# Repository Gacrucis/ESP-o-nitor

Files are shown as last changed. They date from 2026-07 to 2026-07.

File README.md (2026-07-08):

# ESP-o-nitor

A physical usage monitor for Claude and Codex. A host service reads each tool's quota and
activity and feeds an ESP32 display that shows, at a glance, how much of your 5h and weekly
windows is left and whether each tool is working, waiting or idle.

The heavy lifting (reading quota, tracking activity, deciding pace) always happens in the host
service. What changes between builds is only the **display hardware**, so the firmware comes in
two variants that talk to the **same** service:

```
                                   /--HTTP frames--> [OLED ESP32] --I2C--> 2x SSD1306 128x64 (mono)
[monitor-service (PC/Docker)] -----|
   reads quota + activity          \--HTTP JSON----> [CYD ESP32]  --SPI--> 1x ILI9341 320x240 (color)
```

| Variant | Hardware | How it draws |
| --- | --- | --- |
| **OLED** | 2x SSD1306 128x64 mono (I2C), one screen per tool | The service renders the 1-bit framebuffers and the ESP just projects them (`/api/esp/frames`). |
| **CYD** | 1x ILI9341 320x240 color (ESP32-2432S028R "Cheap Yellow Display"), both tools on one screen | The ESP draws in color on-device from a ~1 KB JSON snapshot (`/api/esp/snapshot`). |

Pick one variant per device; the service supports both at once with no changes.

## Repository layout

| Folder | Contents |
| --- | --- |
| [`monitor-service/`](monitor-service/) | Host service (Python). Reads Claude/Codex quota, detects activity, renders the OLED frames and serves everything over HTTP. Includes a live configuration web UI. Shared by both firmware variants. |
| [`firmware/oled/`](firmware/oled/) | OLED firmware (PlatformIO, C++): projects the framebuffers the service renders, animates the activity corner and shows local screensavers. |
| [`firmware/cyd/`](firmware/cyd/) | CYD firmware (PlatformIO, C++): draws both tools in color natively from the JSON snapshot. |
| [`3d-models/`](3d-models/) | Printable enclosure for the OLED dual-screen build (STEP + STL with PNG previews): case and lid for the board plus the base and lids that hold the two screens. |

Each folder has its own README with architecture, requirements and commands.

## Getting started

1. **Host service** ([`monitor-service/`](monitor-service/)): run it with Docker
   (`docker compose up -d --build`) or locally. It serves the web UI at `http://localhost:8765`
   and the `/api/esp/*` endpoints the devices consume. This step is the same for both variants.
2. **Firmware**: build and flash the variant that matches your hardware with PlatformIO (USB or
   OTA), then point the device at the service URL (`http://PC_IP:8765`) from its own
   configuration web page.
   - OLED: [`firmware/oled/`](firmware/oled/)
   - CYD: [`firmware/cyd/`](firmware/cyd/)

## How the pieces fit

- The service builds a usage snapshot (remaining percentage, 5h/weekly windows, expected pace)
  and exposes it under `/api/esp/*`. The OLED variant consumes pre-rendered frames
  (`/api/esp/frames`); the CYD variant consumes the raw snapshot (`/api/esp/snapshot`) and draws
  it in color itself.
- Activity (working / waiting / idle) arrives via long-poll (`/api/esp/activity-wait`) so either
  device reacts almost instantly and drives its activity animation.
- Almost everything (theme, labels, animation, screensaver, brightness, manual usage) is set from
  the service web UI and applied on the device's next poll, without reflashing. You only reflash
  when the firmware itself changes (`firmware/<variant>/src/main.cpp`, its `platformio.ini` or its
  dependencies).

## Development

- **Host service** (`monitor-service/`): runs with hot reload via `watchmedo`, mounting
  `monitor-service/src` into the container. For changes to Python, embedded HTML, CSS or service
  logic there is no need to restart or run Docker; the live service reloads on its own. Validate
  with `python -m compileall monitor-service/src` and, when relevant, against the HTTP endpoints
  of the already running service. Only use Docker commands when the container configuration,
  dependencies, `Dockerfile` or `docker-compose.yml` change, or if the live service stops
  responding.
- **Firmware** (`firmware/oled/`, `firmware/cyd/`): only needs reflashing when that variant's
  `src/main.cpp`, `platformio.ini` or PlatformIO dependencies change. See each variant's README
  for the build and flash commands (USB and OTA).

## License

Released under the MIT License. See [LICENSE](LICENSE).

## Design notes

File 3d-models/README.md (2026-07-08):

# 3d-models

Printable enclosure for the **OLED variant** of ESP-o-nitor ([`../firmware/oled/`](../firmware/oled/)):
the ESP32 dev board plus the two OLED SSD1306 128x64 displays. Each part is provided both as STEP
(ISO 10303, editable in CAD) and as STL (ready to slice).

The **CYD variant** ([`../firmware/cyd/`](../firmware/cyd/)) is not covered here: it is a single
self-contained board (ESP32-2432S028R), so any off-the-shelf horizontal CYD case works - search
"CYD" or "ESP32-2432S028R" on [printables.com](https://www.printables.com/) or
[makerworld.com](https://makerworld.com/).

- [`STEP/`](STEP/) - solid models (FreeCAD, Fusion 360, etc.).
- [`STL/`](STL/) - meshes ready for a slicer (PrusaSlicer, Cura, etc.).
- [`previews/`](previews/) - PNG render of each part.

## Parts

| Part | Qty | Purpose | Preview |
| --- | --- | --- | --- |
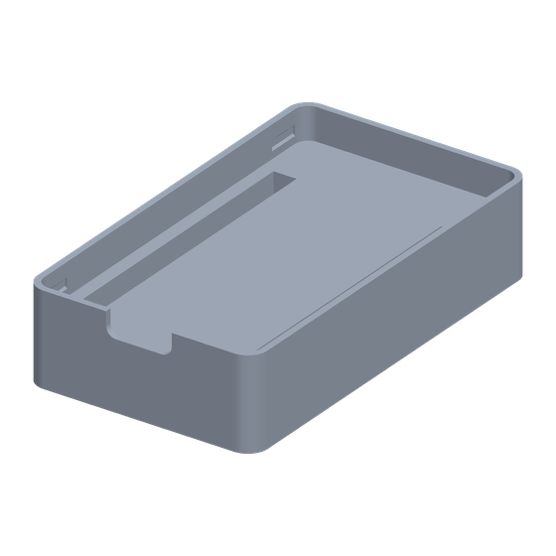
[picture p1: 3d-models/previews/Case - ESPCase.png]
ESPCase
| `Case - ESPCase` | 1 | Housing for the ESP32 board. |  |
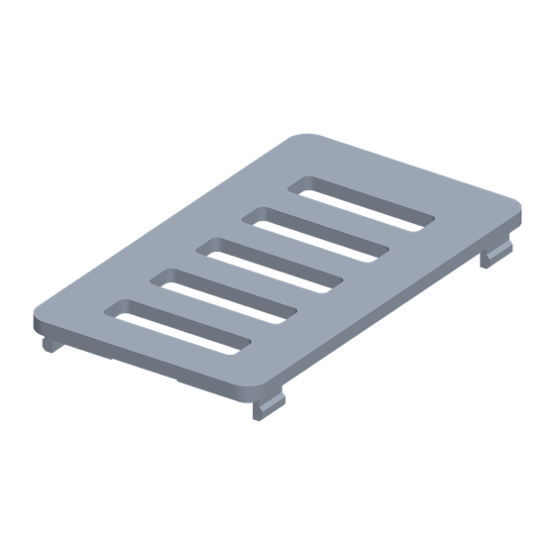
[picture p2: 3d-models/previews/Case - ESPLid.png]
ESPLid
| `Case - ESPLid` | 1 | Lid for the ESP32 housing. |  |
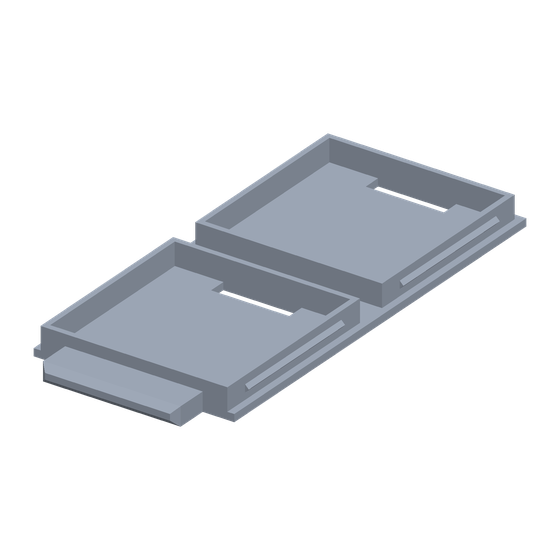
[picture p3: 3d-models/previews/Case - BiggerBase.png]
BiggerBase
| `Case - BiggerBase` | 1 | Base that holds the two OLED SSD1306 (128x64) displays. |  |
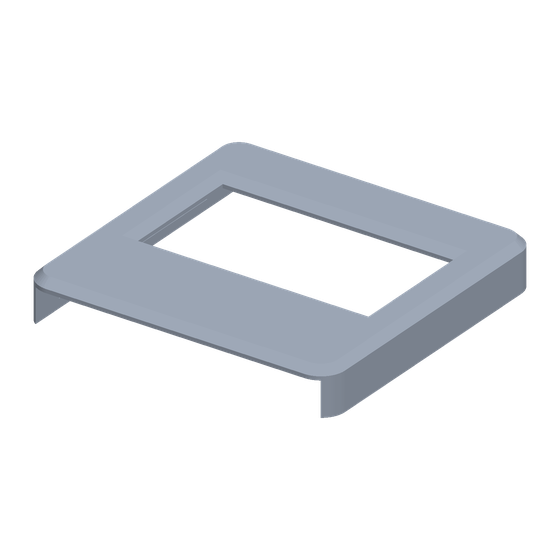
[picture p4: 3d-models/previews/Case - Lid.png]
Lid
| `Case - Lid` | 2 | Bezel/lid for the display base - one per display. |  |

You need **2 units of `Case - Lid`** for the display base (one bezel per screen). Every other part
is printed once. Together they make up the enclosure for the ESP32 and the two screens.

## Notes

- STEP is a solid-model format: open the `STL/` files directly in a slicer to generate the
  printing G-code, or the `STEP/` files in CAD to adjust them.

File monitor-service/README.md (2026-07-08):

# monitor-service

Local service that feeds the [ESP-o-nitor firmware](../firmware/) with Claude and Codex usage. It
reads each tool's quota and activity, and serves it over HTTP to whichever display variant is
connected. It includes a live configuration web UI.

It backs both firmware variants from the same snapshot:

- [OLED](../firmware/oled/): the service renders the two screens (128x64, 1 bit) as framebuffers
  and the device only projects them.
- [CYD](../firmware/cyd/): the service exposes the raw JSON snapshot and the device draws it in
  color itself.

## How it works

- Builds a usage snapshot (remaining percentage, 5h/weekly windows, expected pace). It is served
  raw at `/api/esp/snapshot` (consumed by the CYD).
  - Claude: usage OAuth endpoint.
  - Codex: local `rate_limits` snapshots from the rollouts.
- Renders each OLED screen with Pillow according to the selected theme and serves it as a
  framebuffer at `/api/esp/frames` (with cache and ETag so it is not rebuilt on every ESP poll).
- Detects activity (working / waiting / idle) and delivers it via long-poll so the ESP reacts
  almost instantly.
- Packs the corner animation (configurable style + size) into a binary that the ESP downloads
  once (re-downloaded only if the ETag changes).
- Measures ESP telemetry (last poll, cadence, IP) to show in the web UI whether it is connected
  and when a freshly saved change will take effect.

## Requirements

- Python >= 3.12 and Pillow + watchdog (see `pyproject.toml`), or Docker.
- Read-only access to `~/.claude` and `~/.codex` (where quota and activity are read from).

## Run with Docker (recommended)

```bash
docker compose up -d --build
```

The web UI is at `http://localhost:8765`. The `docker-compose.yml`:

- Mounts `./src` for hot reload (when you edit the code on the host, `watchmedo` restarts the
  service).
- Mounts `~/.claude` and `~/.codex` as read-only.
- Persists the configuration in the `monitor-service-data` volume (`/app/data/config.json`).

Logs and status:

```bash
docker compose ps
docker compose logs --tail 80
```

## Run without Docker

```bash
pip install pillow==11.0.0 watchdog==6.0.0
export CONFIG_PATH=./data/config.json
export CLAUDE_HOME="$HOME/.claude"
export CODEX_HOME="$HOME/.codex"
export SERVICE_HOST=0.0.0.0
export SERVICE_PORT=8765
PYTHONPATH=src python -m monitor_service.main
```

## Environment variables

| Variable | Description |
| --- | --- |
| `CONFIG_PATH` | Path of the persistent `config.json` (required). |
| `CLAUDE_HOME` / `CODEX_HOME` | Claude and Codex directories (read-only). |
| `SERVICE_HOST` / `SERVICE_PORT` | HTTP server host and port. |
| `FRAME_CACHE_TTL_SECONDS` | Minimum interval between ESP frame regenerations. |
| `CLAUDE_USAGE_TTL_SECONDS` | Minimum interval between real Claude usage queries. |
| `CODEX_USAGE_TTL_SECONDS` | Minimum interval between local Codex reads. |

Most settings (theme, labels, animation, screensaver, dimming, manual usage) are edited from the
web UI and saved in `config.json`; the variables only set the initial default values.

## Configuration web UI

`http://localhost:8765` offers:

- Home: Claude/Codex cards, ESP32 device status (live) and a preview of both screens.
- Usage: manual percentages and windows (5h / weekly).
- Settings: labels, tolerance, cache TTLs, anti burn-in dimming, activity animation (style, speed
  and box size), theme and screensavers.

On save, the web UI estimates when it will take effect based on the ESP's real poll cadence and
confirms once the device applies it.

## Main endpoints

Web / configuration:

- `GET /` - web interface.
- `GET /api/config` / `POST /api/config` - read / save configuration.
- `POST /api/usage/manual` - set manual usage.
- `GET /api/status` - diagnostics of paths and sources.
- `GET /api/esp/status` - ESP telemetry (online, last poll, cadence, IP).
- `GET /api/themes` - available themes.

Consumed by the ESP32:

- `GET /api/esp/frames` - framebuffers of both screens (octet-stream, ETag).
- `GET /api/esp/activity-wait` - activity long-poll.
- `GET /api/esp/activity-animation` - binary package of the corner animation.

Previews (web):

- `GET /api/esp/snapshot` - JSON snapshot.
- `GET /api/esp/preview/{claude|codex}.png` - screen preview.
- `GET /api/esp/activity-preview.gif` - animation preview.
- `GET /api/esp/screensaver-preview.gif` - screensaver preview.

## Structure

- `src/monitor_service/main.py` - HTTP server, embedded web UI and endpoints.
- `renderer.py` - screen rendering (delta theme).
- `activity_animation.py` - generation and packaging of the corner animation.
- `screensavers.py` - screensaver previews.
- `usage.py` / `claude_usage.py` / `collectors.py` - quota and activity reading.
- `config.py` / `types.py` - configuration loading, normalization and types.

## Theme and styles

- Screen theme: `delta` (terminal-style columns with remaining %, pace delta and reset, plus a
  solid bar marking the value expected from the linear regression).
- Animation styles: `spinner`, `dots`, `dots-right`, `stars-right`, `pulse`, `bars`, `ball`,
  `wave`, `worm`. The box size is configurable and the animations adapt to it.
- Screensavers (rendered locally by the ESP): `black`, `snake`, `pipes`, `matrix`, `dvd`, `maze`,
  `flower`.

## Development

- With Docker, hot reload is already active; editing `src/` restarts the service on its own.
- Quick validation: `python -m compileall src`.

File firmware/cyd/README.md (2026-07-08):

# ESP-o-nitor - CYD firmware

The **CYD variant** of [ESP-o-nitor](../../): firmware for a **CYD** (Cheap Yellow Display,
ESP32-2432S028R) with a 320x240 color ILI9341 screen that acts as a physical usage monitor for
Claude and Codex.

Unlike the [OLED variant](../oled/), which projects the framebuffers the service renders, the CYD
**draws in color on-device** from the JSON snapshot exposed by the
[monitor-service](../../monitor-service/). Both variants use the same service, unchanged.

## Architecture

```
[monitor-service (PC/Docker)] --HTTP JSON--> [CYD/ESP32] --SPI--> ILI9341 320x240
      computes quota/activity    /api/esp/*     draws       Claude (top) + Codex (bottom)
```

- Polls `GET /api/esp/snapshot` every `pollIntervalMs` and draws both panels.
- Uses `GET /api/esp/activity-wait` (non-blocking long-poll) to react almost instantly to the
  busy / waiting / idle states and animate each tool's activity indicator.
- Only redraws when the data changes (signature comparison); the activity spinner refreshes just
  its own box so the rest of the screen does not flicker.
- If the service does not respond it shows "No service"; if there is no WiFi it brings up a
  configuration AP.

Sending ~1 KB of JSON per poll instead of full framebuffers keeps the wire cheap, exploits the
color panel, and needs no changes on the service side.

## What it shows

For each tool (Claude / Codex), on its half of the screen:

- Icon + name and an activity indicator (BUSY with spinner / WAIT blinking / IDLE).
- The **5H** (current) and **WK** (weekly) windows, each with:
  - Remaining percentage and the delta against what the linear regression expects (+margin ahead
    / -behind).
  - A usage bar colored by pace (green below, blue on pace, amber above, red when very little is
    left) with a vertical mark for the expected value.
  - Time until reset.

## Hardware (ESP32-2432S028R)

- ESP32-WROOM-32 with a 320x240 SPI ILI9341 panel and a resistive XPT2046 touch (unused).
- Panel pinout (fixed by `build_flags` in `platformio.ini`):
  SCLK 14, MOSI 13, MISO 12, CS 15, DC 2, RST -1, backlight (BL) GPIO 21.
- Backlight driven by PWM (LEDC) to dim on inactivity.
- The RGB LED (GPIO 4/16/17, active low) is turned off at boot.

## Requirements

- [PlatformIO](https://platformio.org/) (CLI or VS Code extension).
- Dependencies (resolved by PlatformIO): TFT_eSPI, ArduinoJson.

## Credentials (WiFi and OTA)

1. Copy `include/secrets.example.h` to `include/secrets.h` and set the SSID, WiFi password, OTA
   password and (optionally) the default service URL. `secrets.h` is ignored by git.
2. For OTA flashing, copy `platformio_override.example.ini` to `platformio_override.ini` with the
   same OTA password in `--auth`.

Without `secrets.h` it builds with empty values: the CYD boots into the `CYD-Emergencia` AP
(password `configcyd0`) and you configure WiFi/service from `http://192.168.4.1`.

## Build and flash

Run from this `firmware/cyd/` folder.

**Linux.** The CYD reuses the OLED variant's PlatformIO `.venv`, so no separate install is needed:

```bash
# Build
../oled/.venv/bin/python3 -m platformio run -e cyd
# Flash over USB (the CYD ships a CH340, usually /dev/ttyUSB0)
../oled/.venv/bin/python3 -m platformio run -e cyd -t upload --upload-port /dev/ttyUSB0
# Flash over OTA (with the CYD on the network as cyd.local)
../oled/.venv/bin/python3 -m platformio run -e cyd_ota -t upload
```

**macOS.** The bundled `.venv/` is a local Linux artifact and is not in the repository, so install
PlatformIO once and use the system `pio` (replace `../oled/.venv/bin/python3 -m platformio` with
`pio` in every command above):

```bash
brew install platformio          # or: pip3 install platformio
# Build
pio run -e cyd
# Flash over USB (the CYD ships a CH340; on macOS it shows up as /dev/cu.wchusbserial*)
pio run -e cyd -t upload --upload-port /dev/cu.wchusbserial-0001
# Flash over OTA
pio run -e cyd_ota -t upload
```

- On macOS use the `cu.*` node, never `tty.*`. If the port does not appear, install the WCH CH34x
  driver (the CYD uses a CH340 USB-serial chip). There is no `dialout` group or `sudo`: the port
  works as-is.
- List the available ports with `pio device list` (or `.venv/bin/python3 -m platformio device list`
  on Linux).

If USB upload fails, lower `upload_speed` in `platformio.ini` (921600 -> 460800 -> 115200).

## Configuration

Booting without valid WiFi brings up the `CYD-Emergencia` AP. Connect and open
`http://192.168.4.1` to set the SSID, password and service URL (`http://PC_IP:8765`). Once on the
network the CYD is reachable at `http://cyd.local` to reconfigure the service, rotation,
brightness, dimming and poll interval, and for web OTA.

## Structure

- `src/main.cpp` - the entire firmware (setup, loop, WiFi/AP, web, OTA, polling and rendering).
- `platformio.ini` - build environments and the TFT_eSPI configuration for the CYD.

## Relationship with the service

This firmware depends on the service in [monitor-service/](../../monitor-service/), which exposes
the `/api/esp/*` endpoints. It consumes `GET /api/esp/snapshot` (data) and
`GET /api/esp/activity-wait` (activity long-poll). It also hits `GET /api/esp/frames` with an
`If-None-Match`, but only to read the `X-Sessions-*` session-count headers off the 304 response;
it never downloads the framebuffer. Theme colors, labels, brightness and usage data
are set in the service web UI and applied on the next poll, without reflashing. You only reflash
when `src/main.cpp`, `platformio.ini` or the PlatformIO dependencies change.

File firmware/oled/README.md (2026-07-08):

# ESP-o-nitor - OLED firmware

The **OLED variant** of [ESP-o-nitor](../../): firmware for an ESP32 with two SSD1306 OLED
displays (128x64) that act as a physical usage monitor for Claude and Codex. The ESP32 computes
nothing: it only projects the framebuffers produced by the [monitor-service](../../monitor-service/),
animates the activity corner and shows local screensavers when the service does not respond.

For the color single-screen build see the [CYD variant](../cyd/); both talk to the same service.

## Architecture

```
[monitor-service (PC/Docker)]  --HTTP-->  [ESP32]  --I2C-->  2x OLED SSD1306
        renders 128x64 1-bit             projects            Claude / Codex
```

- The service draws each screen (128x64, 1 bit) and serves it at `/api/esp/frames`.
- The ESP32 polls that endpoint and copies the bitmap straight to the OLED (it never interprets
  the content).
- Activity (working / waiting / idle) arrives via long-poll and headers, and drives the animation
  in the top-right corner; while waiting for a response the screen blinks inverted.
- The animation package is downloaded once and kept in RAM; it is re-downloaded only if its ETag
  changes.
- If the service is down, the ESP shows a local screensaver (anti burn-in).

## Hardware

- Board: ESP32 dev (`board = esp32dev`).
- 2x OLED SSD1306 128x64 over I2C, on separate buses (one `TwoWire` per display).
- Default I2C pins (configurable from the ESP web UI):
  - Claude: SDA 21, SCL 22, address `0x3C`.
  - Codex: SDA 16, SCL 17, address `0x3C`.

## Features

- Projection of 128x64 framebuffers from the service.
- Activity animation in the corner (size and style configurable from the service).
- Blinking screen inversion when a tool is waiting for the user.
- Local anti burn-in screensavers: black, snake, pipes, matrix, dvd, maze, flower.
- Brightness dimming on inactivity (decided by the service via the `X-Brightness` header).
- Built-in web server on port 80 to configure WiFi, service URL, pins and displays.
- Emergency AP mode when it cannot connect to WiFi (portal at `http://192.168.4.1`).
- Network OTA (ArduinoOTA, port 3232) and web OTA.
- Configuration persistence in NVS (`Preferences`).
- mDNS: the device is reachable as `esp32.local`.

## Structure

- `src/main.cpp` - the entire firmware (setup, loop, web server, OTA, rendering, screensavers).
- `platformio.ini` - build environments and dependencies.

## Requirements

- [PlatformIO](https://platformio.org/) (CLI or VS Code extension).
- Dependencies (resolved automatically by PlatformIO): Adafruit SSD1306, Adafruit GFX,
  ArduinoJson.

## Credentials (WiFi and OTA)

The firmware ships no credentials in the source. To set local default values:

1. Copy `include/secrets.example.h` to `include/secrets.h` and put your SSID, WiFi password and
   OTA password there. You may also set `SECRET_SERVICE_URL` to your PC's service URL (leave it
   empty to configure it later from the web UI). That file is ignored by git and never versioned.
2. For OTA flashing, copy `platformio_override.example.ini` to `platformio_override.ini` and put
   the same OTA password in `--auth`. PlatformIO applies it automatically on top of
   `platformio.ini`; it is ignored by git too.

Without `secrets.h`, the firmware builds with empty credentials: the ESP boots into the emergency
AP and you configure WiFi/service from its web UI. The OTA password must match between
`secrets.h` (running firmware) and `platformio_override.ini` (OTA upload).

## Build and flash

### Toolchain (PlatformIO in the project `.venv`)

All commands in this section run from the `esp32/` folder (where `platformio.ini` and `.venv/`
live).

PlatformIO 6.1.19 lives in the project `.venv`. The `.venv/bin/pio` launcher kept a shebang
inherited from another project (it points to a non-existent Python), so the module is invoked
with the venv's Python, which does work:

```bash
.venv/bin/python3 -m platformio <command>
```

To get `pio` back directly, reinstall the launcher once:

```bash
.venv/bin/python3 -m pip install --force-reinstall platformio
```

(If you already have PlatformIO on the system PATH, just use `pio <command>`.)

**macOS**: the bundled `.venv/` is a local Linux artifact and is not part of the repository, so on
Mac you install PlatformIO separately (once) and use the system `pio`:

```bash
brew install platformio          # or: pip3 install platformio
pio run -e esp32dev              # replaces `.venv/bin/python3 -m platformio ...`
```

In the rest of this guide, replace `.venv/bin/python3 -m platformio` with `pio`.

### Over USB (first flash or if OTA fails)

Connect the ESP32 over USB. PlatformIO auto-detects the serial port; force it with `--upload-port`
if there are several devices. To list the available ports:

```bash
.venv/bin/python3 -m platformio device list
```

```bash
.venv/bin/python3 -m platformio run -e esp32dev -t upload
# explicit port, optional:
.venv/bin/python3 -m platformio run -e esp32dev -t upload --upload-port <port>
```

**Linux**

- Typical ports: `/dev/ttyUSB0` (CP210x/CH340 chip) or `/dev/ttyACM0` (native USB).
- If the port is permission denied, add your user to the `dialout` group
  (`sudo usermod -aG dialout $USER`) and restart the session.

**macOS**

- Typical ports: `/dev/cu.usbserial-*` or `/dev/cu.SLAB_USBtoUART` (CP210x),
  `/dev/cu.wchusbserial*` (CH340). Always use the `cu.*` node, not `tty.*`.
- Modern macOS (11+) already ships the CP210x and CH340 drivers. If the port does not appear,
  install the chip vendor's driver: Silicon Labs CP210x VCP or WCH CH34x.
- There is no `dialout` group or permission tweak: the port works without `sudo`.

```bash
# example on macOS with an explicit port:
.venv/bin/python3 -m platformio run -e esp32dev -t upload --upload-port /dev/cu.usbserial-0001
```

### Over OTA (with the ESP already on the network, reachable as `esp32.local`)

```bash
.venv/bin/python3 -m platformio run -e esp32dev_ota -t upload
# if mDNS does not resolve, point at the ESP's IP:
.venv/bin/python3 -m platformio run -e esp32dev_ota -t upload --upload-port 192.168.1.xxx
```

The `esp32dev_ota` environment uses `espota` against `esp32.local` with the password defined in
`platformio_override.ini` (`--auth=...`, see [Credentials](#credentials-wifi-and-ota)). It must
match the OTA password of the running firmware; if you change one, change the other.

### Build only (no upload)

```bash
.venv/bin/python3 -m platformio run -e esp32dev
```

The default WiFi and OTA credentials come from `include/secrets.h` (see
[Credentials](#credentials-wifi-and-ota)); at runtime they are changed from the ESP web UI.

## First boot and configuration

1. After flashing, if the ESP cannot connect to the configured WiFi, it brings up the emergency
   AP `ESP32-Emergencia`. Connect to it and open `http://192.168.4.1`.
2. Configure the SSID, password and the service URL (for example `http://PC_IP:8765`).
3. Once on the network, the ESP is reachable at `http://esp32.local` to reconfigure pins,
   displays, contrast and to check status.

## Relationship with the service

This firmware depends on the service in [monitor-service/](../../monitor-service/), which exposes the
`/api/esp/*` endpoints the ESP consumes. Changes to animation style/size, theme, screensavers,
brightness and usage data are made in the service web UI and applied on the ESP's next poll,
without reflashing. You only need to reflash when `src/main.cpp`, `platformio.ini` or the
PlatformIO dependencies change.

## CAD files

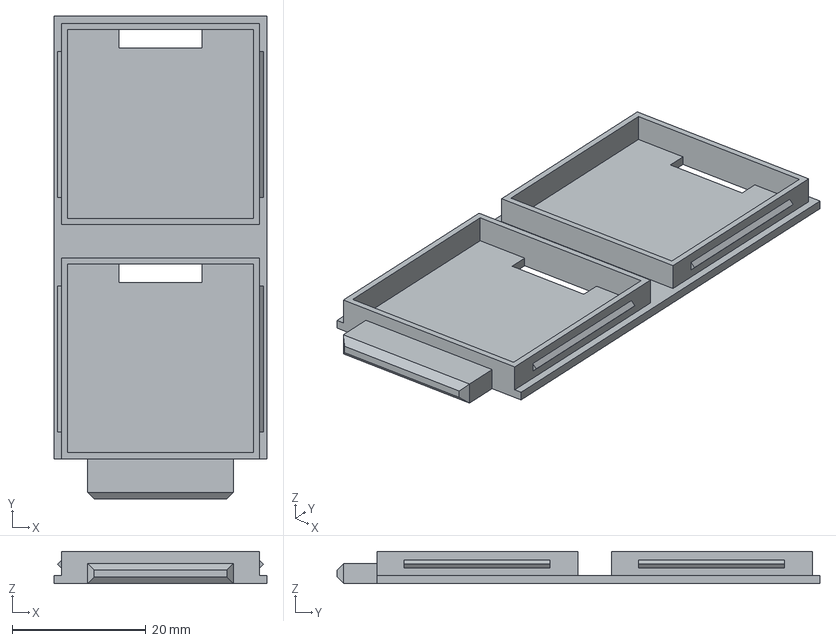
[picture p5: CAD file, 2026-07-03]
3d-models/STEP/Case - BiggerBase.step
31.8 x 72.1 x 4.80 mm

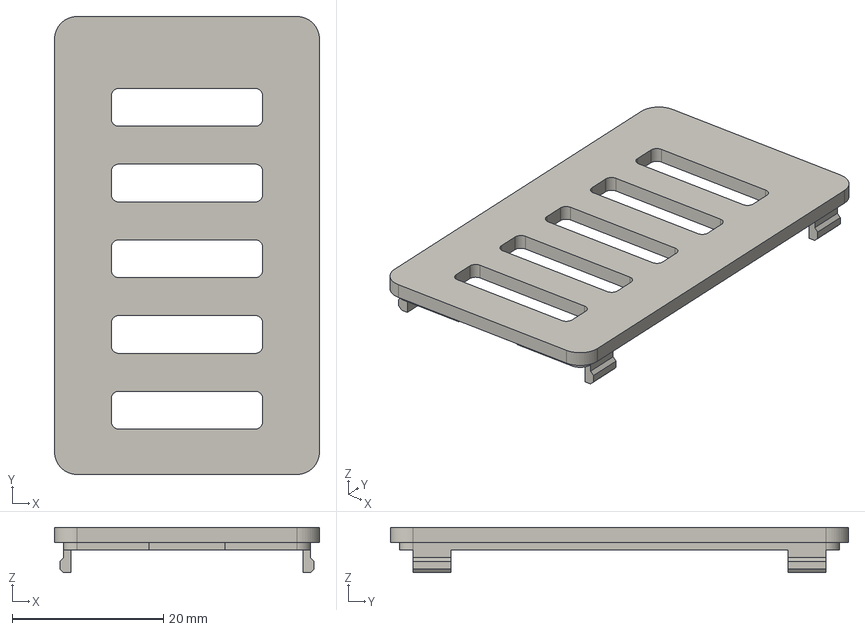
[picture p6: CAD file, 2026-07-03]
3d-models/STEP/Case - ESPLid.step
35.0 x 60.5 x 6.00 mm

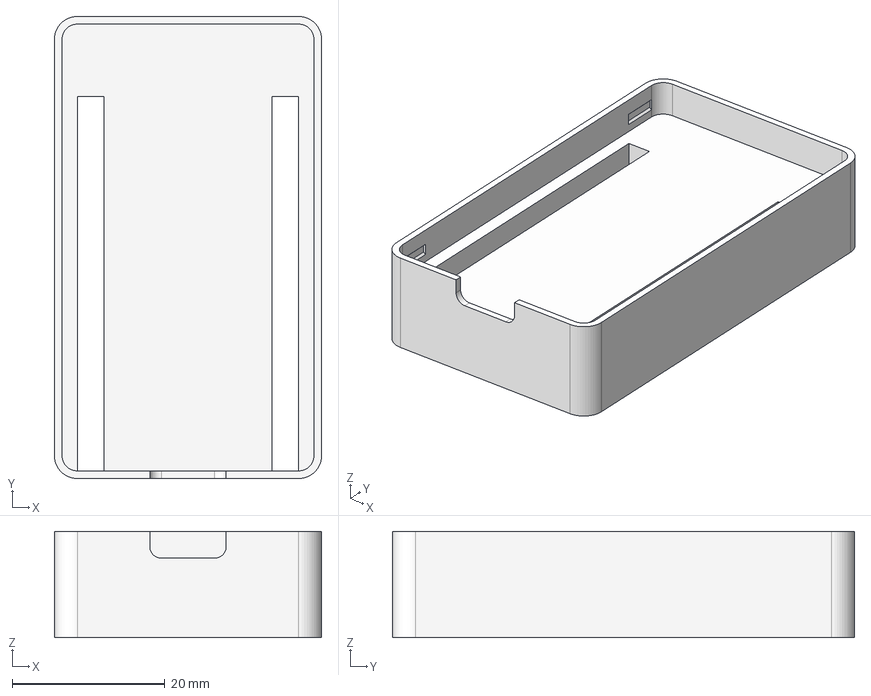
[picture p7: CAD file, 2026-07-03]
3d-models/STEP/Case - ESPCase.step
35.0 x 60.5 x 13.9 mm

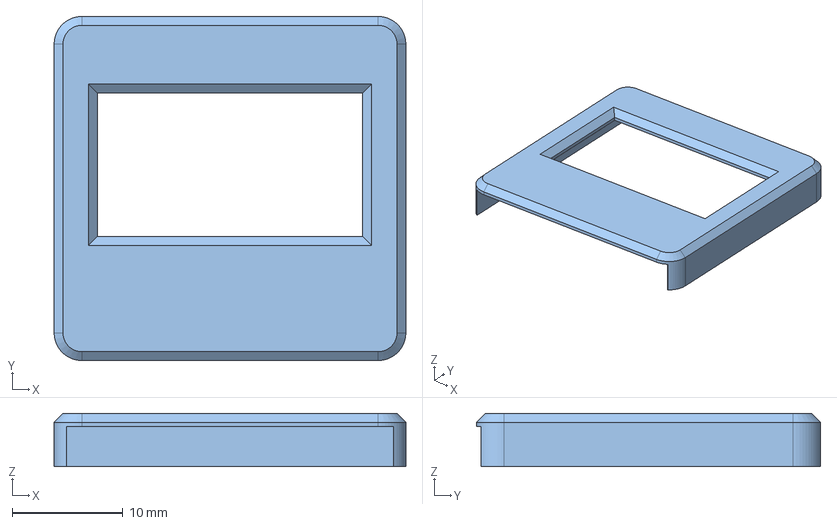
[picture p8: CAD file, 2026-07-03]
3d-models/STEP/Case - Lid.step
31.8 x 31.1 x 4.80 mm

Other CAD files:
3d-models/STL/Case - BiggerBase.stl
3d-models/STL/Case - ESPCase.stl
3d-models/STL/Case - ESPLid.stl
3d-models/STL/Case - Lid.stl

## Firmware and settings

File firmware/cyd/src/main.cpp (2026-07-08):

#include <Arduino.h>
#include <ArduinoJson.h>
#include <ArduinoOTA.h>
#include <ESPmDNS.h>
#include <FS.h>
#include <HTTPClient.h>
#include <LittleFS.h>
#include <Preferences.h>
#include <SD.h>
#include <SPI.h>
#include <TFT_eSPI.h>
#include <Update.h>
#include <WebServer.h>
#include <WiFi.h>
#include <esp_task_wdt.h>
#include <esp_core_dump.h>
#include <esp_partition.h>
#include <esp_system.h>

// Las credenciales por defecto viven en secrets.h (ignorado por git). Si no existe,
// se compila con valores vacios y el CYD arranca en el AP de emergencia.
#if __has_include("secrets.h")
#include "secrets.h"
#endif
#ifndef SECRET_WIFI_SSID
#define SECRET_WIFI_SSID ""
#endif
#ifndef SECRET_WIFI_PASSWORD
#define SECRET_WIFI_PASSWORD ""
#endif
#ifndef SECRET_OTA_PASSWORD
#define SECRET_OTA_PASSWORD ""
#endif
#ifndef SECRET_SERVICE_URL
#define SECRET_SERVICE_URL ""
#endif
#ifndef SECRET_WEB_PASSWORD
#define SECRET_WEB_PASSWORD ""
#endif

// ---------------------------------------------------------------------------
// Constantes de red, identidad y hardware del CYD.
// ---------------------------------------------------------------------------

const uint16_t HTTP_PORT = 80;
const char WEB_USER[] = "admin"; // usuario de la auth basica de la web (usuario admin)
const char DEFAULT_WEB_PASSWORD[] = SECRET_WEB_PASSWORD; // clave web por defecto; vacia = web abierta
const uint32_t MIN_ONLINE_CYCLE_MS = 500; // piso de cadencia del sondeo online (anti busy-loop)
const char ESP_HOSTNAME[] = "cyd";
const char LOCAL_DOMAIN[] = "cyd.local";
const char OTA_HOSTNAME[] = "cyd";
const char OTA_PASSWORD[] = SECRET_OTA_PASSWORD;
const char DEFAULT_WIFI_SSID[] = SECRET_WIFI_SSID;
const char DEFAULT_WIFI_PASSWORD[] = SECRET_WIFI_PASSWORD;
const char DEFAULT_SERVICE_URL[] = SECRET_SERVICE_URL;
const char EMERGENCY_AP_SSID[] = "CYD-Emergencia";
const char EMERGENCY_AP_PASSWORD[] = "configcyd0";
const char EMERGENCY_AP_URL[] = "http://192.168.4.1";

// El LED RGB del CYD (GPIO 4/16/17) es activo en bajo: se fuerza a HIGH para apagarlo.
const uint8_t RGB_LED_PINS[] = {4, 16, 17};
// PENIRQ del tactil XPT2046: se pone en LOW al tocar la pantalla (sin SPI ni calibracion).
const uint8_t TOUCH_IRQ_PIN = 36;
// Ranura microSD del CYD (bus HSPI propio; el TFT usa VSPI, no chocan).
const uint8_t SD_CS_PIN = 5;
const uint8_t SD_SCLK_PIN = 18;
const uint8_t SD_MISO_PIN = 19;
const uint8_t SD_MOSI_PIN = 23;
const char LOG_FILE_PATH[] = "/cyd-log.txt";
const uint32_t LOG_FILE_MAX_BYTES = 5242880; // 5MB antes de rotar
const uint8_t LOG_FILE_KEEP = 5;             // cantidad de archivos rotados que se conservan
const char BACKUP_DIR[] = "/backups";
const char COREDUMP_DIR[] = "/coredumps"; // volcados de crash guardados en la SD
const uint8_t COREDUMP_KEEP = 3;          // LIMITE: solo se conservan los ultimos N (rota por slot)
// Version del esquema de config: se guarda en cada backup para poder migrar en el futuro.
// Subirla cuando cambie la ESTRUCTURA de config (campos nuevos/renombrados).
const uint16_t CONFIG_VERSION = 2; // v2: incluye paleta completa + tendencia + tamano de cuadros
// Retroiluminacion por PWM (LEDC) para poder atenuar (anti burn-in).
const uint8_t BL_LEDC_CHANNEL = 0;
const uint32_t BL_LEDC_FREQ = 5000;
const uint8_t BL_LEDC_BITS = 8;

// Dimensiones de la pantalla en horizontal (rotacion 1/3).
const int16_t SCREEN_W = 320;
const int16_t SCREEN_H = 240;
const int16_t PANEL_H = SCREEN_H / 2; // Un panel por herramienta (Claude arriba, Codex abajo).

// Tiempos del sondeo.
const uint32_t WIFI_CONNECT_TIMEOUT_MS = 20000;
const uint32_t SNAPSHOT_HTTP_TIMEOUT_MS = 4000;

// ---------------------------------------------------------------------------
// Configuracion persistente (NVS) y estado de ejecucion.
// ---------------------------------------------------------------------------

struct AppConfig
{
    String wifiSsid;
    String wifiPassword;
    String serviceUrl;
    uint32_t pollIntervalMs;
    uint8_t rotation;         // 1 o 3 (horizontal). Permite girar 180 grados.
    uint8_t brightnessPct;    // Brillo activo (0-100).
    uint8_t dimBrightnessPct; // Brillo atenuado por inactividad (0-100).
    uint32_t dimAfterSec;     // Segundos de inactividad total antes de atenuar (0 = desactivado).
    bool invertDisplay;       // Inversion de color del ILI9341 (el CYD suele necesitarla).
    uint8_t animSpeed;        // Velocidad del marquee busy (px por tick, 1-15).
    int16_t animBoxX;         // Borde izquierdo del area de animacion (px, 110-280).
    String waitTitle;         // Titulo grande del panel de pregunta (waiting).
    String waitMsg;           // Mensaje del panel de pregunta; se le antepone el nombre.
    String webPassword;       // Clave de la auth web (usuario admin). Vacia = web abierta.
    uint8_t screensaver;      // Screensaver offline: 0 off, 1 matrix, 2 dvd, 3 stars, 4 snake.
    String claudeColor;       // Color de acento de Claude, hex "RRGGBB".
    String codexColor;        // Color de acento de Codex, hex "RRGGBB".
    String textColor;         // Color del texto principal (digitos del reset), hex "RRGGBB".
    String mutedColor;        // Color del texto secundario/gris (5H, WK, unidades H/D/M), hex "RRGGBB".
    uint16_t trendWindowMin;  // Ventana para la tendencia del superavit, en minutos.
    uint8_t trendMarginPct;   // Margen muerto de la tendencia (puntos %); dentro de +-margen = estable.
    uint8_t animSquarePx;     // Tamano (px) de los cuadrados de la animacion busy, 4-14.
    // Paleta completa configurable (todos hex "RRGGBB"). Los acentos y textos ya existen arriba.
    String bgColor;           // Fondo de la pantalla.
    String dividerColor;      // Linea divisora de cada panel.
    String barBgColor;        // Fondo de las barras de uso.
    String goodColor;         // Positivo (tendencia arriba, estados OK).
    String warnColor;         // Advertencia.
    String badColor;          // Negativo (deficit, tendencia abajo, errores).
    String disabledColor;     // Texto/marcas de estado deshabilitado / idle.
    uint8_t alertThresholdPct; // Si el % restante <= este umbral, el numero y la barra van en rojo. 0 = off.
    String claudeLabel;       // Alias local para Claude (vacio = usar el nombre del servicio).
    String codexLabel;        // Alias local para Codex (vacio = usar el nombre del servicio).
    uint8_t animStyle;        // Estilo de la animacion busy: 0 marquee, 1 pulso, 2 barra.
    uint16_t alertBlinkMs;    // Periodo del parpadeo de la alerta de pregunta (ms). 0 = panel fijo.
    uint8_t animHz;           // Cadencia (fps/Hz) de la animacion de actividad: 10-60.
};

// Datos de una ventana de uso (5h o semanal) tal como los entrega el snapshot.
struct WindowData
{
    float remaining = 0.0f;   // remaining_percent
    float expected = 0.0f;    // expected_remaining_percent (regresion lineal)
    String pace;              // under / on_track / over / unknown
    long resetSeconds = 0;    // reset_in_seconds
};

// Estado de una herramienta (Claude o Codex).
struct ToolData
{
    String label;
    bool enabled = true;
    String activity = "idle"; // idle / busy / waiting
    String statusText;
    WindowData current;
    WindowData weekly;
};

struct MonitorState
{
    bool online = false;
    String lastError;
    ToolData claude;
    ToolData codex;
    uint32_t lastPollMs = 0;
    uint32_t lastActivityChangeMs = 0;
};

// Paleta (se llena en setup con color565).
struct Palette
{
    uint16_t bg;
    uint16_t panelDivider;
    uint16_t textPrimary;
    uint16_t textMuted;
    uint16_t barBg;
    uint16_t good;
    uint16_t ok;
    uint16_t warn;
    uint16_t bad;
    uint16_t muted;
    uint16_t claude;
    uint16_t codex;
    uint16_t tick;
};

WebServer server(HTTP_PORT);
Preferences preferences;
TFT_eSPI tft = TFT_eSPI();

AppConfig config;
MonitorState monitorState;
Palette pal;

bool emergencyWifiActive = false;
bool needsFullRedraw = true;
uint32_t lastAnimTickMs = 0;
uint8_t appliedBrightnessPct = 255; // Fuerza aplicar el brillo la primera vez.
uint8_t brightnessTargetPct = 100;  // Objetivo hacia el que converge appliedBrightnessPct (rampa suave).

// Sprite fuera de pantalla del tamano de un panel: los paneles se dibujan aqui y se
// vuelcan de una sola vez (pushSprite), eliminando el flicker del redibujado directo.
TFT_eSprite panelSprite = TFT_eSprite(&tft);
// Franja pequena para animar la actividad "busy" volcando SOLO su area (no los 320x120 del
// panel): reduce muchisimo el SPI por frame y con ello el tearing (lineas diagonales).
TFT_eSprite stripSprite = TFT_eSprite(&tft);
bool stripReady = false;
// Aviso de pregunta: el panel invertido se vuelca UNA vez (base estable) y solo parpadea un
// banner "INPUT" en una franja chica (titleSprite) -> el flash no vuelca los 320x120 = sin tearing.
// Sprite overlay COMPARTIDO del aviso de pregunta (una sola reserva, en setup): en el se dibujan
// y vuelcan por separado, en su posicion, tanto el icono+nombre (arriba) como "INPUT"+subtitulo
// (centro). Volcados chicos -> sin tearing; una sola reserva -> sin fragmentar el heap.
const int16_t OVL_W = 300, OVL_H = 44; // ancho para que 34 chars entren a escala 2 fija (sin achicar)
TFT_eSprite ovlSprite = TFT_eSprite(&tft);
bool ovlReady = false;
bool waitBase[2] = {false, false}; // base (fondo acento) ya dibujada (0=claude, 1=codex)

// Reserva/libera un sprite bajo demanda (para tener el maximo heap libre en idle online).
// bpp: profundidad de color. Los sprites de 2 colores (alerta, franja busy) usan 4bpp con paleta
// (1/4 de RAM que 16bpp, colores EXACTOS via createPalette); el resto usa 16bpp.
bool ensureSprite(TFT_eSprite &spr, bool &ready, int16_t w, int16_t h, uint8_t bpp)
{
    if (!ready)
    {
        spr.setColorDepth(bpp);
        ready = (spr.createSprite(w, h) != nullptr);
    }
    return ready;
}
void freeSprite(TFT_eSprite &spr, bool &ready)
{
    if (ready)
    {
        spr.deleteSprite();
        ready = false;
    }
}

// Almacenamiento: LittleFS (FS interno) y tarjeta SD (bus HSPI propio). Los logs van a
// la SD si esta presente; si no, se quedan solo en RAM (evita desgastar la flash interna).
SPIClass sdSpi(HSPI);
bool sdReady = false;
bool littleFsReady = false;

// Parpadeo del panel invertido cuando hay una pregunta (waiting).
bool blinkOn = false;
uint32_t lastBlinkMs = 0;

// Overlay de diagnostico al tocar la pantalla (toggle con cada toque).
bool infoOverlayActive = false;
uint32_t lastOverlayDrawMs = 0;

// Metricas de red para el overlay (las actualiza la tarea de sondeo; lectura de uint32
// es atomica en ESP32, sirve para mostrar).
volatile uint32_t statLastPollMs = 0;
volatile uint32_t statLastSuccessMs = 0;
volatile uint32_t statPollCount = 0;
volatile uint32_t statFailCount = 0;
volatile uint32_t pollHeartbeat = 0;              // incrementa al tope de cada vuelta de pollTask
const uint32_t POLL_STALL_MS = 120000;            // sin latido tanto tiempo = pollTask colgado -> reinicio
// Ritmo del loop de render (core1) como proxy de carga de CPU: vueltas por segundo.
uint32_t loopCount = 0, loopHz = 0, lastHzMs = 0, lastHzCount = 0;

// Sesiones (agentes) trabajando en paralelo por herramienta, de las cabeceras
// X-Sessions-* del servicio. Definen cuantos puntos muestra la animacion "dots-right".
uint8_t claudeSessions = 1;
uint8_t codexSessions = 1;
String framesEtag = "";
// Desplazamiento del marquee de cuadrados de la animacion busy (contador libre; se mueve
// a la derecha). Es uint32 para que solo haya discontinuidad al desbordar (nunca en la practica).
uint32_t dotScroll = 0;

// Tendencia del superavit por bloque (0 Claude 5H, 1 Claude WK, 2 Codex 5H, 3 Codex WK).
// Se guarda un historico corto de muestras y se compara el superavit actual contra el de
// hace config.trendWindowMin minutos para saber si subio (+1), bajo (-1) o quedo dentro del
// margen (0). Se dibuja una flecha/punto a la derecha del delta de cada ventana.
const uint8_t TREND_BLOCKS = 4;
const uint8_t TREND_SAMPLES = 48;
const uint32_t RECENT_TREND_MS = 360000UL; // la flecha reacciona al uso de los ultimos ~6 min (no promedia la ventana entera)
struct TrendSample
{
    uint32_t ms;
    float surplus;
};
struct TrendHist
{
    TrendSample s[TREND_SAMPLES];
    uint8_t count;
    uint8_t head;
};
TrendHist trendHist[TREND_BLOCKS] = {};
int8_t trendDir[TREND_BLOCKS] = {0, 0, 0, 0};

bool webOtaError = false;
bool webOtaRestartPending = false;
uint32_t webOtaRestartAtMs = 0;
String webOtaStatus = "Listo para subir firmware.";

// Sondeo HTTP en una tarea del segundo nucleo (core 0): asi el loop de render/animacion
// (core 1) nunca se bloquea esperando a la red y la animacion no se traba. La tarea
// publica el estado en incomingState bajo mutex; el loop lo copia a monitorState y dibuja
// (todo el acceso a la TFT ocurre solo en el loop, nunca en la tarea).
SemaphoreHandle_t stateMutex = nullptr;
// Protege las lecturas/escrituras de los String de config compartidos entre core0 (pollTask)
// y core1 (handlers web). pollTask copia serviceUrl/pollInterval bajo este mutex al inicio de
// cada ciclo; los handlers lo toman al mutar config (evita use-after-free del buffer del String).
SemaphoreHandle_t configMutex = nullptr;
TaskHandle_t pollTaskHandle = nullptr;
MonitorState incomingState;
volatile bool incomingReady = false;
bool spriteReady = false;   // el sprite de panel se creo correctamente
bool wifiDownDrawn = false;  // ya se dibujo el aviso de WiFi caido (evita repintar)

// Prototipos de funciones referenciadas antes de su definicion.
String getActiveWifiSsidSafe();
String normHexColor(const String &hex, const String &def);

// ---------------------------------------------------------------------------
// Utilidades.
// ---------------------------------------------------------------------------

String jsonEscape(const String &value)
{
    String out = "";
    out.reserve(value.length() + value.length() / 8 + 8); // evita cientos de reallocaciones (logBuffer ~8KB)
    for (size_t i = 0; i < value.length(); i++)
    {
        const char c = value.charAt(i);
        if (c == '"' || c == '\\')
        {
            out += '\\';
            out += c;
        }
        else if (c == '\n')
        {
            out += "\\n";
        }
        else if (c == '\r')
        {
            out += "\\r";
        }
        else if (c == '\t')
        {
            out += "\\t";
        }
        else
        {
            out += c;
        }
    }
    return out;
}

// Formatea segundos restantes como duracion legible: XDdYh / HhMMm / Mm.
String formatDuration(long seconds)
{
    if (seconds < 0)
    {
        seconds = 0;
    }
    const long minutes = seconds / 60;
    const long hours = minutes / 60;
    if (hours >= 24)
    {
        return String(hours / 24) + "D" + String(hours % 24) + "H";
    }
    if (hours >= 1)
    {
        char buffer[12];
        snprintf(buffer, sizeof(buffer), "%ldH%02ldM", hours, minutes % 60);
        return String(buffer);
    }
    return String(minutes) + "M";
}

// Texto del delta remaining - expected: +N% (margen) o -N% (pasado de ritmo).
String formatDelta(const WindowData &window)
{
    const int delta = (int)lround(window.remaining - window.expected);
    if (delta >= 0)
    {
        return String("+") + String(delta) + "%";
    }
    return String(delta) + "%";
}

float clamp01(float value)
{
    if (value < 0.0f)
    {
        return 0.0f;
    }
    if (value > 100.0f)
    {
        return 100.0f;
    }
    return value;
}

// ---------------------------------------------------------------------------
// Configuracion persistente.
// ---------------------------------------------------------------------------
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
void loop()
{
    esp_task_wdt_reset(); // alimenta el watchdog: si el loop se cuelga, reinicia y se recupera solo
    // Ritmo del loop (proxy de CPU): vueltas por segundo, calculado cada 1s (costo nulo).
    loopCount++;
    if (millis() - lastHzMs >= 1000)
    {
        loopHz = loopCount - lastHzCount;
        lastHzCount = loopCount;
        lastHzMs = millis();
    }

    server.handleClient();
    if (!emergencyWifiActive)
    {
        ArduinoOTA.handle();
    }

    if (webOtaRestartPending && millis() >= webOtaRestartAtMs)
    {
        ESP.restart();
    }

    if (emergencyWifiActive)
    {
        return;
    }

    // Watchdog de la tarea de red (core0): el WDT de tarea solo vigila este loop (core1). Si
    // pollTask se cuelga (mutex huerfano, wedge de socket/lwip pese a los timeouts), el loop
    // seguiria vivo y el CYD quedaria congelado con datos viejos SIN reiniciar. Cierra el lazo del
    // latido: si con WiFi conectado pollHeartbeat no avanza en POLL_STALL_MS (mayor que el peor
    // long-poll ~60s, para no dar falsos positivos), la tarea esta atascada -> reinicia y recupera.
    static uint32_t lastHb = 0;
    static uint32_t lastHbMs = 0;
    const uint32_t hbNow = millis();
    if (pollHeartbeat != lastHb || lastHbMs == 0)
    {
        lastHb = pollHeartbeat;
        lastHbMs = hbNow;
    }
    else if (WiFi.status() == WL_CONNECTED && hbNow - lastHbMs > POLL_STALL_MS)
    {
        logAt(LVL_ERROR, "pollTask sin latido " + String((hbNow - lastHbMs) / 1000) + "s -> reinicio de recuperacion");
        delay(50); // deja salir el log a SD antes de reiniciar
        ESP.restart();
    }

    // Reconexion WiFi simple (la tarea de red espera mientras tanto).
    static uint32_t lastWifiReconnectMs = 0;
    if (WiFi.status() != WL_CONNECTED)
    {
        // Avisa una sola vez que se perdio el WiFi (no deja datos viejos como vigentes).
        if (!wifiDownDrawn)
        {
            monitorState.online = false;
            if (config.screensaver == 0)
            {
                drawOfflineScreen("Sin WiFi");
            }
            logAt(LVL_WARN, "WiFi perdido; reconectando");
            wifiDownDrawn = true;
            WiFi.reconnect();
            lastWifiReconnectMs = millis();
        }
        else if (millis() - lastWifiReconnectMs > 8000)
        {
            // Reintenta con backoff (8s), NO cada vuelta: llamar reconnect() cada 200ms reinicia
            // la asociacion/DHCP en curso y alarga la recuperacion.
            WiFi.reconnect();
            lastWifiReconnectMs = millis();
        }
        // Permite gestionar el toque (abrir/cerrar el overlay) tambien sin WiFi: si no, un overlay
        // abierto quedaria congelado y sin poder cerrarse durante toda la caida, y bloqueando el
        // screensaver. handleTouch tambien lo refresca (mostrando que esta offline).
        handleTouch();
        // Libera los sprites de estados online (busy/waiting) que no aplican offline: el bloque
        // freeSprite del final del loop no se alcanza por el return de abajo, asi que sin esto se
        // retendrian ~33KB de heap durante toda la caida.
        freeSprite(stripSprite, stripReady);
        freeSprite(ovlSprite, ovlReady);
        // Sin WiFi tambien corre el screensaver (anti burn-in) en vez de quedar estatico.
        if (!infoOverlayActive)
        {
            runScreensaver();
        }
        delay(200);
        return;
    }
    if (wifiDownDrawn)
    {
        // Se recupero el enlace: fuerza un redibujado completo en la proxima publicacion.
        wifiDownDrawn = false;
        needsFullRedraw = true;
        saverActive = false;
        logLine("WiFi recuperado: " + WiFi.localIP().toString());
    }

    // Toque de pantalla: muestra/oculta el overlay de diagnostico.
    handleTouch();

    // Aplica el estado sondeado por la tarea y anima; el render nunca se bloquea por la red.
    // (consumeIncomingState y animateActivity no dibujan mientras el overlay esta arriba).
    consumeIncomingState();

    // Mientras hay servicio, resetea el reloj de gracia offline.
    if (monitorState.online)
    {
        offlineSinceMs = millis();
    }

    // Preview forzado desde la web (prioritario), o screensaver offline tras la gracia
    // (para no lanzarlo al arrancar mientras llega el primer dato).
    const bool previewSaver = (saverPreviewId != 0 && millis() < saverPreviewUntilMs);
    const bool offlineSaver = (!monitorState.online && config.screensaver != 0 && millis() - offlineSinceMs >= SAVER_GRACE_MS);
    if (!infoOverlayActive && (previewSaver || offlineSaver))
    {
        runScreensaver();
    }
    else
    {
        if (saverActive)
        {
            // Se salio del screensaver: redibuja el monitor/offline.
            saverActive = false;
            needsFullRedraw = true;
            if (monitorState.online)
            {
                renderMonitor();
            }
        }
        animateActivity();
    }
    updateBrightness();
    rampBrightness(); // converge suave hacia el objetivo (rampa anti-escalon)

    // Libera los sprites que no se usan ahora (deja el maximo heap libre para el snapshot JSON).
    const bool busyNow = monitorState.online && (monitorState.claude.activity == "busy" || monitorState.codex.activity == "busy");
    const bool waitNow = monitorState.online && (monitorState.claude.activity == "waiting" || monitorState.codex.activity == "waiting");
    if (!busyNow)
    {
        freeSprite(stripSprite, stripReady);
    }
    if (!waitNow)
    {
        freeSprite(ovlSprite, ovlReady);
    }
    if (!saverActive)
    {
        freeSprite(dvdSprite, dvdSpriteReady);
    }
}

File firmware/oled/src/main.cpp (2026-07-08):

#include <Adafruit_GFX.h>
#include <Adafruit_SSD1306.h>
#include <Arduino.h>
#include <ArduinoJson.h>
#include <ArduinoOTA.h>
#include <ESPmDNS.h>
#include <HTTPClient.h>
#include <Preferences.h>
#include <Update.h>
#include <WebServer.h>
#include <WiFi.h>
#include <Wire.h>

// Local credentials: copy include/secrets.example.h to include/secrets.h (git-ignored)
// and put your WiFi and OTA password (and, optionally, your service URL) there. Without that
// file, empty defaults are used and the ESP boots into the emergency AP to be configured from
// its web page.
#if __has_include("secrets.h")
#include "secrets.h"
#endif
#ifndef SECRET_WIFI_SSID
#define SECRET_WIFI_SSID ""
#endif
#ifndef SECRET_WIFI_PASSWORD
#define SECRET_WIFI_PASSWORD ""
#endif
#ifndef SECRET_OTA_PASSWORD
#define SECRET_OTA_PASSWORD ""
#endif
#ifndef SECRET_SERVICE_URL
#define SECRET_SERVICE_URL ""
#endif

const uint32_t SERIAL_BAUD_RATE = 115200;
const uint16_t HTTP_PORT = 80;
const uint16_t OTA_PORT = 3232;
const uint16_t OLED_WIDTH = 128;
const uint16_t OLED_HEIGHT = 64;
const uint32_t WIFI_RETRY_DELAY_MS = 500;
const uint32_t WIFI_CONNECT_TIMEOUT_MS = 20000;
// Margin over the HTTPClient 5s default: the service can take several seconds to
// build a new frame (cache miss) and a short timeout triggers
// HTTPC_ERROR_READ_TIMEOUT (-11) and leaves the screen in ellipsis mode.
const uint16_t HTTP_CLIENT_TIMEOUT_MS = 15000;
// Separate short connect timeout: if the service host is powered off (does not
// reject, it simply never answers the SYN), connect() blocks until the timeout
// expires. With the screensaver active that freezes the animation, so the probe
// must fail fast and keep the long read timeout only for slow frames.
const uint16_t HTTP_CONNECT_TIMEOUT_MS = 2000;
// Activity long-poll: non-blocking connection the ESP keeps open to react
// instantly (thinking/done/needs attention) without polling the frame.
const uint16_t ACTIVITY_CONNECT_TIMEOUT_MS = 3000;
const uint32_t ACTIVITY_LONGPOLL_TIMEOUT_MS = 30000;
const uint32_t ACTIVITY_LONGPOLL_RETRY_MS = 1000;
const size_t ACTIVITY_RESPONSE_MAX_BYTES = 512;

// Screensaver (anti burn-in when the service is down). Ids aligned with the
// service (config SCREENSAVERS) and the X-Saver header.
const uint8_t SAVER_BLACK = 0;
const uint8_t SAVER_SNAKE = 1;
const uint8_t SAVER_PIPES = 2;
const uint8_t SAVER_MATRIX = 3;
const uint8_t SAVER_DVD = 4;
const uint8_t SAVER_MAZE = 5;
const uint8_t SAVER_FLOWER = 6;
const uint8_t SAVER_DEFAULT = SAVER_DVD;
// After this time without service, the ESP switches to the screensaver instead of a fixed image.
const uint32_t SAVER_GRACE_MS = 15000;
const uint32_t SAVER_FRAME_MS = 40;
const uint32_t RESTART_DELAY_MS = 1200;
const uint32_t DEFAULT_POLL_INTERVAL_MS = 10000;
const uint32_t PERIODIC_STATUS_LOG_INTERVAL_MS = 60000;
const char ESP_HOSTNAME[] = "esp32";
const char LOCAL_DOMAIN[] = "esp32.local";
const char OTA_HOSTNAME[] = "esp32";
const char OTA_PASSWORD[] = SECRET_OTA_PASSWORD;
const char DEFAULT_WIFI_SSID[] = SECRET_WIFI_SSID;
const char DEFAULT_WIFI_PASSWORD[] = SECRET_WIFI_PASSWORD;
const char EMERGENCY_AP_SSID[] = "ESP32-Emergencia";
const char EMERGENCY_AP_PASSWORD[] = "configesp32";
const char EMERGENCY_AP_URL[] = "http://192.168.4.1";
const char DEFAULT_SERVICE_URL[] = SECRET_SERVICE_URL;
const size_t SERIAL_LOG_MAX_LENGTH = 8000;
const uint8_t BOOT_LOG_MAX_LINES = 8;
const uint8_t BOOT_LOG_MAX_CHARS = 21;
// Boot screen: mascot on the left + logs on the right inside a frame.
const int16_t BOOT_MASCOT_CX = 22;       // X center of the mascot column
const int16_t BOOT_MASCOT_CY = 24;       // Y center of the mascot
const int16_t BOOT_DIVIDER_X = 43;       // vertical divider between mascot and logs
const int16_t BOOT_LOG_X = 47;           // horizontal start of the logs
const int16_t BOOT_LOG_TOP = 4;          // top margin of the logs
const uint8_t BOOT_LOG_LINE_CHARS = 13;  // characters per line next to the mascot
const uint8_t BOOT_LOG_LINE_COUNT = 7;   // visible log lines next to the mascot

// Box reserved in the top-right corner for the activity animation.
// The real size (width x height) arrives in the header of the packet the service sends
// (frame_width/frame_height from config) so it can be adjusted dynamically. The box
// is anchored to the right edge: X = OLED_WIDTH - frameW, Y = 0.
const uint16_t ACTIVITY_BOX_Y = 0;
// Cap the firmware accepts from the packet (must match ANIM_FRAME_MAX_* on the
// service). If the service asks for more, the packet is dropped as out of range.
const uint16_t ACTIVITY_BOX_MAX_W = OLED_WIDTH;
const uint16_t ACTIVITY_BOX_MAX_H = 16;

// Binary animation packet the ESP downloads and stores (not reflashed).
const uint8_t ANIM_PACK_MAGIC = 0xA1;
const uint8_t ANIM_PACK_VERSION = 1;
const uint8_t ANIM_PACK_HEADER_BYTES = 10;
// Buffer sized for the maximum configurable box (128x16) with the maximum number of
// frames (32, worm style): ceil(128/8)*16*32 = 8192 bytes.
const size_t ANIM_MAX_BYTES = 8192;
const uint8_t ANIM_MAX_FRAMES = 32;

struct DisplaySettings
{
    bool enabled;
    uint8_t sdaPin;
    uint8_t sclPin;
    uint8_t address;
    uint8_t contrast;
};

struct WifiSettings
{
    String ssid;
    String password;
};

struct EspSettings
{
    WifiSettings wifi;
    String serviceUrl;
    uint32_t pollIntervalMs;
    DisplaySettings claudeDisplay;
    DisplaySettings codexDisplay;
};

struct MonitorState
{
    bool serviceOnline;
    String serviceError;
    uint32_t lastPollMs;
    uint32_t lastSuccessMs;
    uint64_t frameUpdatedAtMs;
};

WebServer server(HTTP_PORT);
Preferences preferences;
TwoWire claudeWire = TwoWire(0);
TwoWire codexWire = TwoWire(1);
Adafruit_SSD1306 claudeOled(OLED_WIDTH, OLED_HEIGHT, &claudeWire, -1);
Adafruit_SSD1306 codexOled(OLED_WIDTH, OLED_HEIGHT, &codexWire, -1);

EspSettings settings;
MonitorState monitorState;
bool claudeDisplayReady = false;
bool codexDisplayReady = false;
bool webOtaError = false;
bool webOtaRestartPending = false;
uint32_t webOtaRestartAtMs = 0;
String webOtaStatus = "Ready to upload firmware.";
size_t webOtaBytes = 0;
String serialLogBuffer = "";

// Framebuffers the PC draws and the ESP32 only projects (128x64 = 1024 bytes).
const size_t FRAME_BYTES = 1024;
const size_t FRAMES_TOTAL_BYTES = FRAME_BYTES * 2;
uint8_t claudeFrame[FRAME_BYTES];
uint8_t codexFrame[FRAME_BYTES];
bool framesReceived = false;
String frameEtag = "";
uint8_t ellipsisStep = 0;

// Activity animation: frames + parameters the service defines and the ESP stores.
struct ActivityAnimation
{
    bool valid;
    uint8_t frameW;
    uint8_t frameH;
    uint8_t frameCount;
    uint16_t frameBytes;
    uint16_t intervalMs;
    uint16_t blinkMs;
    bool invertOnWaiting;
};

// Runtime state of the animation/inversion per physical screen.
struct DisplayActivityRuntime
{
    bool animActive;
    uint8_t animIndex;
    uint32_t lastAnimStepMs;
    bool invertOn;
    uint32_t lastInvertToggleMs;
};
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

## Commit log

2026-07-03 feat: ESP-o-nitor - monitor fisico de uso de Claude y Codex
    Monorepo con tres componentes:
    - esp32/: firmware PlatformIO (C++) que proyecta las pantallas OLED, anima la
    actividad y muestra salvapantallas locales.
    - monitor-service/: servicio host (Python) que lee la cuota de Claude/Codex,
    renderiza las pantallas (tema delta) y las sirve por HTTP con web de config.
    - 3d-models/: carcasa imprimible (STEP) para el ESP32 y las dos pantallas.
    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
    [Case - BiggerBase.step, Case - ESPCase.step, Case - ESPLid.step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]
2026-07-03 feat(3d-models): agrega STL y previews PNG, separa STEP/STL
    - Reorganiza en carpetas STEP/ y STL/ (mallas listas para slicer)
    - Agrega render PNG isometrico de cada pieza en previews/
    - Documenta cantidades: 2x Case - Lid para la base de pantallas
    - .gitignore: versiona los previews de 3d-models pese al *.png global
    [Case - BiggerBase.step, Case - BiggerBase.stl, Case - ESPCase.step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]
2026-07-03 fix(3d-models): previews mas limpios y STL con teselado mas fino
    - Render con z-buffer real, backface culling y antialiasing (sin scribbles
    de wireframe ni geometria interior traspasando las paredes)
    - Teselado STEP mas fino: curvas suaves y STL de mejor calidad
    [Case - ESPCase.stl, Case - ESPLid.stl, Case - Lid.stl]
2026-07-03 fix(config): migrate legacy Spanish status_text to English on load
    Persisted configs saved before the English switch stored status_text
    'Sin datos recientes'; map it to 'No recent data' so the no-data sentinel
    in usage.py keeps matching and the UI no longer shows the stale Spanish text.
2026-07-08 feat: unifica OLED y CYD en un repo reorganizado, portable y endurecido
    Integra el firmware CYD (ESP32-2432S028R, ILI9341 a color) en el repositorio del
    monitor y lo reorganiza como un unico producto con un servicio compartido y dos
    variantes de firmware segun el hardware de pantalla.
    Estructura:
    - firmware/oled/ (2x SSD1306, era esp32/) y firmware/cyd/ (CYD a color) como pares
    - monitor-service/ y 3d-models/ compartidos; .gitignore consolidado
    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
